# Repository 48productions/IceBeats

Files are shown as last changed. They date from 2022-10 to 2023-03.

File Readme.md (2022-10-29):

# IceBeats Music Visualizer
*"it's like a firebeat, but **cooler**"*

## Introduction
IceBeats is a Teensy-based lights driver board that does two things:
 - Works with StepMania to control cabinet and pad lights in a 573-era DDR cabinet.
 - Real-time, hardware independent music visualization across two LED strips.

The hardware is designed for minimal components/configuration for an embedded environment.
Grab a Teensy 3.2, a few addressable LED strips, and a few basic components, and you're done! No bloated bluetooth/wifi control or complex hardware setup required.

## Features
Code support for these are built-in - all 99% configurable, use any combination you like!

 * Visualization addressable LED strip - An addressable RGB LED strip for visualizations.
 * Bass addressable LED strip - Another addressable RGB LED strip, blinks to the beat.
 * Bass single-color LED strip/strand - Designed for a single-color LED strip, or low voltage LED string lights. Blinks to the beat.
     * Supports two-wire LED strands, where alternate LEDs/colors are driven by reversing the strip polarity using a H-Bridge, like the L293D. These are cheap and readibly available off places like Amazon.

 * Accepts audio input via RCA/mono 3.5mm jack (or with modification, any other input the Teensy audio library supports)
 * Designed around Teensy 3.2, other Audio-capable Teensy boards likely compatible (the 4.0 is untested but may work)
 
 * FFT-based music visualization using the Teensy Audio Library
 * Multiple visualization effects and color palettes. Optional dynamic, music-based color palettes available
 * Idle animations for when no music is playing
 
 * Drives 573-era DanceDanceRevolution cabinet/pad lighting (reads SextetStream-formatted data output by StepMania or other programs).
 * PCB design

## Hardware Setup
**Pin numbers and LED strip lengths can ALL be configured in `IceBeats.ino` - the settings are at the top!**

### Audio Input
Audio input is taken via a 3.5mm/RCA jack. [Wiring instructions can be found on the Teensy Audio Design Tool](https://www.pjrc.com/teensy/gui/?info=AudioInputAnalog)'s info panel for AudioInputAnalog.

### Visualization LED strip:
The main attraction, music visualization on an addressable LED strip!

Any WS2812/NeoPixel strip will do here (default: 54 pixels long, but can be configured for shorter/longer strips).
Excessive pixel count may cause performance drops.

### Bass LED strip:
This blinks to the beat with a strip-wide gradient, occasionally changing colors.

Again, use any WS2812/NeoPixel strip (default: 128 pixels. This can be made shorter/longer too)

### Bass light strand:
This one just blinks to the beat! You've got a few options for this:

For a single-color LED strip/string, one PWM pin is used for setting the strip's brightness, just hook it up to a mosfet/transistor and you're good to go.
  
Some cheap LED strings on Amazon will control alternate LEDs, or different LED colors by reversing the strip polarity.
If you have one of these strings, a L293D can be used to drive the strip at two different polarities to turn on alternate LEDs/colors.
Another pin can optionally connect to a L293D to do this. You will need to invert that pin's signal via a transistor, inverter, etc to drive the second input on the L293D.

### StepMania pad/cab light control:
This code accepts input over serial for any games/tools that use the SextetStream protocol for driving DDR cabinet/pad lights.

In the case of StepMania, this means either using the SextetStreamToFile (Linux) or Win32Serial (Windows) lights driver.

The light states are sent to the rest of the Teensy's IO pins. Ideally, these should connect to the DDR cabinet through opto isolators. No transistor/mosfet is needed here, the stock DDR cabinet amp handles the high-current loads.

Lights data can optionally be output to three shift registers, as well, if you need more light outputs than the Teensy has pins.

## Todo:
 There's a lotta things that could be improved
 * Better documentation/wiring instructions
 * A few bugfixes with idle animations on the main led strip
 * Better beat detection
 * Getting the visualizations to look like they reflect the music a bit closer
 * More color palettes.

## License
I'd greatly apprecate it if you credit/link back to this repo if you use this code somewhere - this thing took a TON of time to make.

That being said,

¯\\_(ツ)_/¯

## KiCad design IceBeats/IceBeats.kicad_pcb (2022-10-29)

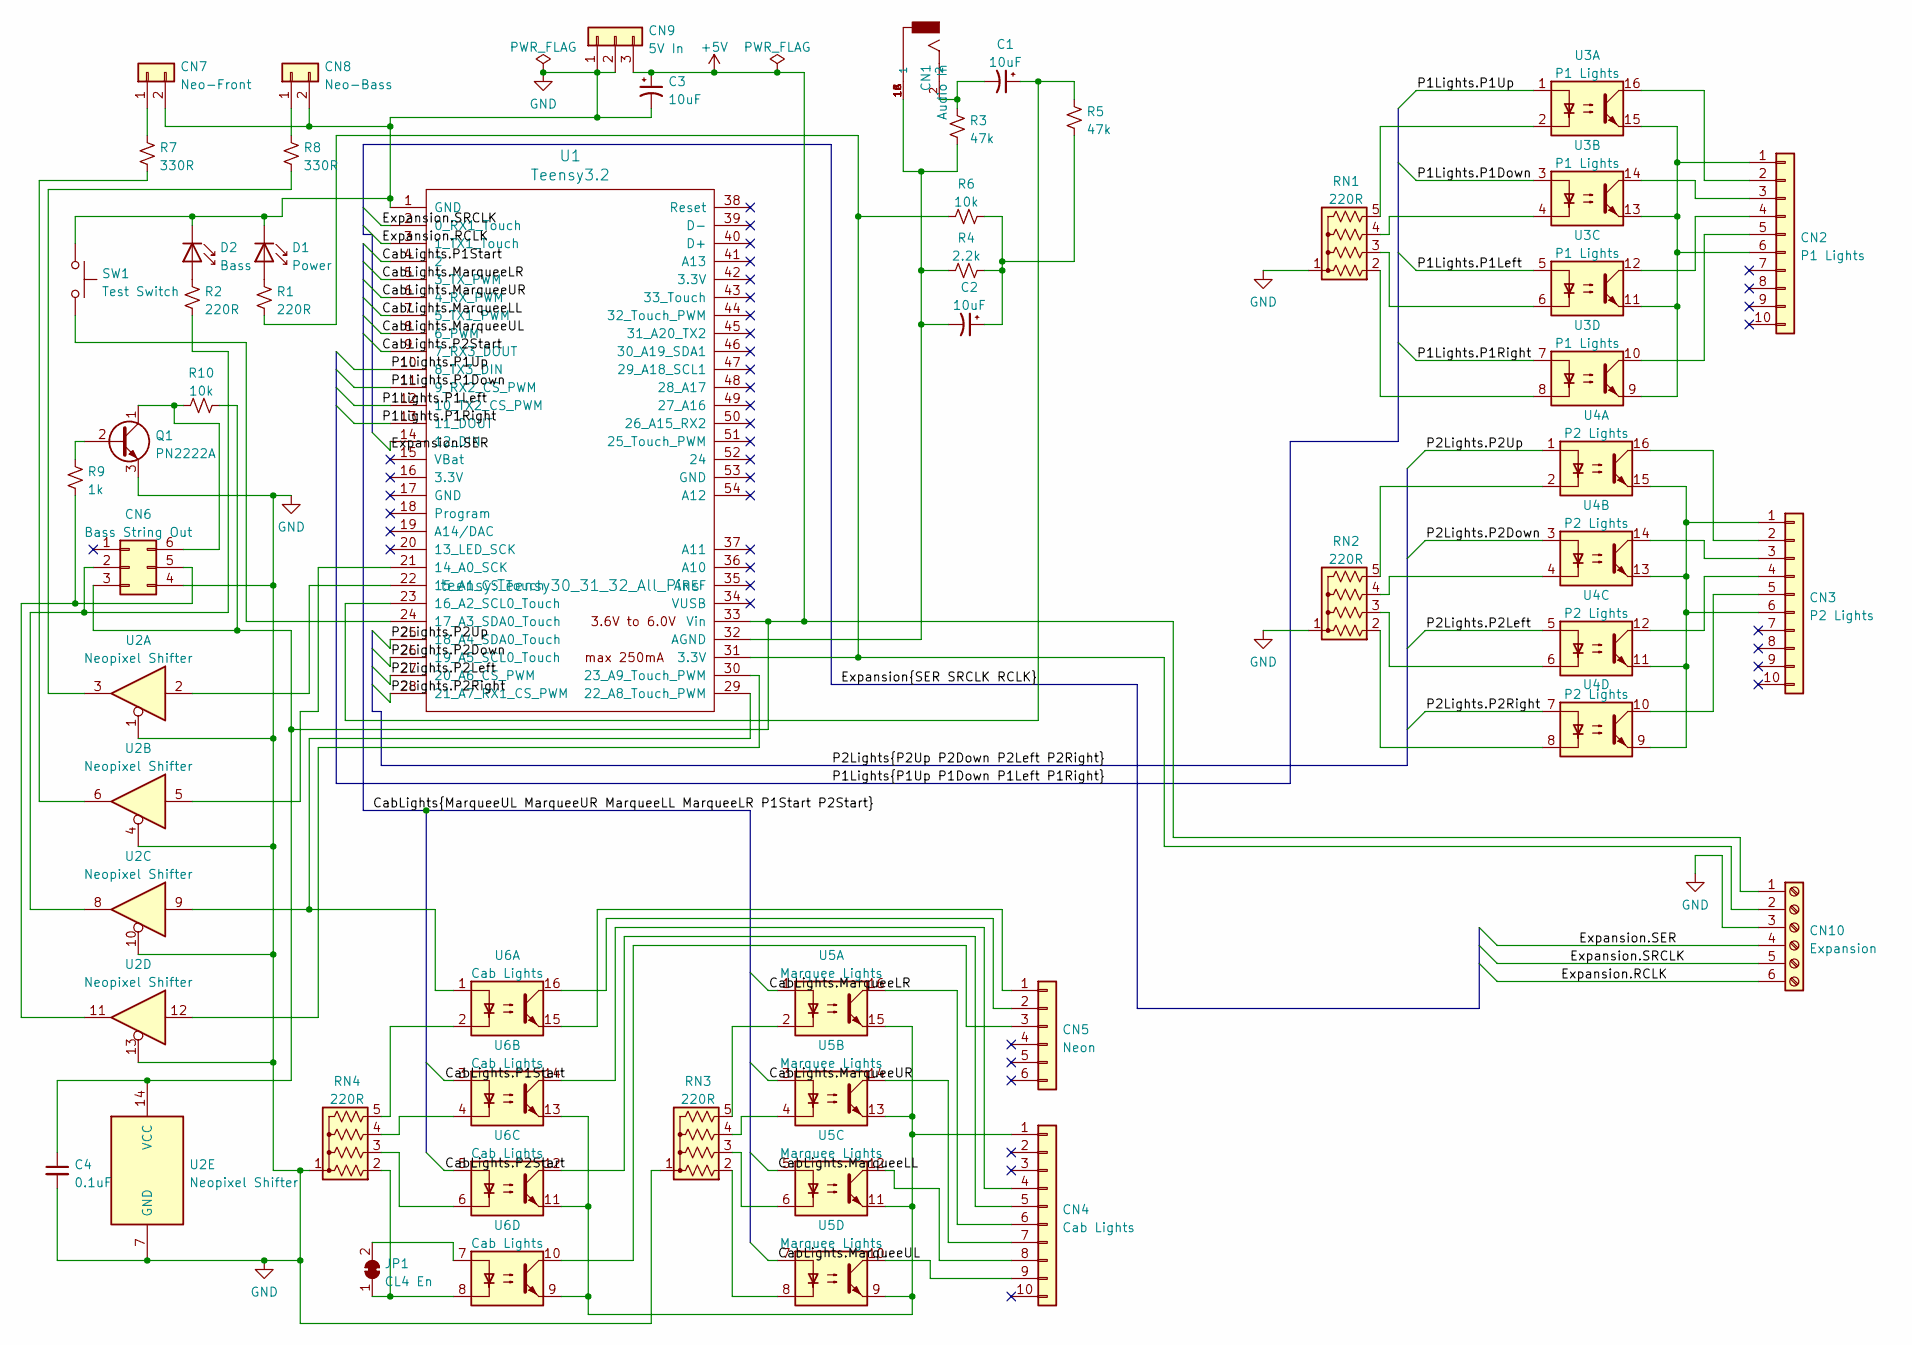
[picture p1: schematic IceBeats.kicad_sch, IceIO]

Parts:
C1, C2, C3: 10uF; CP_Radial_D6.3mm_P2.50mm
C4: 0.1uF; C_Disc_D5.1mm_W3.2mm_P5.00mm
CN1: Audio In; CUI_RCJ-013; PART_REV B
CN2: P1 Lights; PinHeader_1x10_P2.54mm_Vertical
CN3: P2 Lights; PinHeader_1x10_P2.54mm_Vertical
CN4: Cab Lights; PinHeader_1x10_P2.54mm_Vertical
CN5: Neon; PinHeader_1x06_P2.54mm_Vertical
CN6: Bass String Out; IDC-Header_2x03_P2.54mm_Vertical
CN7: Neo-Front; Molex_KK-254_AE-6410-02A_1x02_P2.54mm_Vertical
CN8: Neo-Bass; Molex_KK-254_AE-6410-02A_1x02_P2.54mm_Vertical
CN9: 5V In; Molex_KK-254_AE-6410-03A_1x03_P2.54mm_Vertical
CN10: Expansion; PinHeader_1x06_P2.54mm_Vertical
D1: Power; LED_D3.0mm_Horizontal_O3.81mm_Z2.0mm
D2: Bass; LED_D3.0mm_Horizontal_O3.81mm_Z2.0mm
JP1: CL4 En; SolderJumper-2_P1.3mm_Bridged_RoundedPad1.0x1.5mm
Q1: PN2222A; TO-92_HandSolder
R1, R2: 220R; R_Axial_DIN0207_L6.3mm_D2.5mm_P2.54mm_Vertical
R3: 47k; R_Axial_DIN0207_L6.3mm_D2.5mm_P2.54mm_Vertical
R4: 2.2k; R_Axial_DIN0207_L6.3mm_D2.5mm_P10.16mm_Horizontal
R5: 47k; R_Axial_DIN0207_L6.3mm_D2.5mm_P10.16mm_Horizontal
R6, R10: 10k; R_Axial_DIN0207_L6.3mm_D2.5mm_P10.16mm_Horizontal
R7, R8: 330R; R_Axial_DIN0207_L6.3mm_D2.5mm_P10.16mm_Horizontal
R9: 1k; R_Axial_DIN0207_L6.3mm_D2.5mm_P10.16mm_Horizontal
RN1, RN2, RN3, RN4: 220R; R_Array_SIP5
SW1: Test Switch; SW_PUSH_6mm_H5mm
U1: Teensy3.2; Teensy30_31_32_All_Pins
U2: Neopixel Shifter; DIP-14_W7.62mm_Socket
U3: P1 Lights; DIP-16_W7.62mm
U4: P2 Lights; DIP-16_W7.62mm
U5: Marquee Lights; DIP-16_W7.62mm
U6: Cab Lights; DIP-16_W7.62mm

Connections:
+5V: C3.1, C4.1, CN6.3, CN9.3, CN10.1, R10.1, U1.33 (Vin), U2.14 (VCC)
/CabLights.MarqueeLL: U1.7 (5_TX1_PWM), U5.5
/CabLights.MarqueeLR: U1.5 (3_TX_PWM), U5.1
/CabLights.MarqueeUL: U1.8 (6_PWM), U5.7
/CabLights.MarqueeUR: U1.6 (4_RX_PWM), U5.3
/CabLights.P1Start: U1.4 (2), U6.3
/CabLights.P2Start: U1.9 (7_RX3_DOUT), U6.5
/Expansion.RCLK: CN10.6, U1.3 (1_TX1_Touch)
/Expansion.SER: CN10.4, U1.14 (12_DIN)
/Expansion.SRCLK: CN10.5, U1.2 (0_RX1_Touch)
/P1Lights.P1Down: U1.11 (9_RX2_CS_PWM), U3.3
/P1Lights.P1Left: U1.12 (10_TX2_CS_PWM), U3.5
/P1Lights.P1Right: U1.13 (11_DOUT), U3.7
/P1Lights.P1Up: U1.10 (8_TX3_DIN), U3.1
/P2Lights.P2Down: U1.26 (19_A5_SCL0_Touch), U4.3
/P2Lights.P2Left: U1.27 (20_A6_CS_PWM), U4.5
/P2Lights.P2Right: U1.28 (21_A7_RX1_CS_PWM), U4.7
/P2Lights.P2Up: U1.25 (18_A4_SDA0_Touch), U4.1
GND: C3.2, C4.2, CN6.4, CN7.2, CN8.2, CN9.1, CN9.2, CN10.3, D1.1 (K), D2.1 (K), Q1.3 (E), RN1.1 (common), RN2.1 (common), RN3.1 (common), RN4.1 (common), SW1.1, U1.1 (GND), U2.1, U2.4, U2.7 (GND), U2.10, U2.13
unnamed: C1.1, R5.1, U1.23 (16_A2_SCL0_Touch)
unnamed: C1.2, CN1.2, R3.1
unnamed: C2.1, R4.1, R5.2, R6.1
unnamed: C2.2, CN1.1A (1), CN1.1B (1), CN1.1C (1), R3.2, R4.2, U1.32 (AGND)
unnamed: CN2.1, CN2.6, U3.9, U3.11, U3.13, U3.15
unnamed: CN2.2, U3.16
unnamed: CN2.3, U3.14
unnamed: CN2.4, U3.12
unnamed: CN2.5, U3.10
unnamed: CN3.1, CN3.6, U4.9, U4.11, U4.13, U4.15
unnamed: CN3.2, U4.16
unnamed: CN3.3, U4.14
unnamed: CN3.4, U4.12
unnamed: CN3.5, U4.10
unnamed: CN4.1, U5.9, U5.11, U5.13, U5.15, U6.9, U6.11, U6.13
unnamed: CN4.4, U6.14
unnamed: CN4.5, U6.12
unnamed: CN4.6, U5.16
unnamed: CN4.7, U5.14
unnamed: CN4.8, U5.12
unnamed: CN4.9, U5.10
unnamed: CN5.1, U6.15
unnamed: CN5.2, U6.16
unnamed: CN5.3, U6.10
unnamed: CN6.2, R2.2, U2.8
unnamed: CN6.5, R9.2, U2.11
unnamed: CN6.6, Q1.1 (C), R10.2
unnamed: CN7.1, R7.1
unnamed: CN8.1, R8.1
unnamed: CN10.2, R1.2, R6.2, U1.31 (3.3V)
unnamed: D1.2 (A), R1.1
unnamed: D2.2 (A), R2.1
unnamed: JP1.1 (A), RN4.2 (R1), U6.8
unnamed: JP1.2 (B), U6.7
unnamed: Q1.2 (B), R9.1
unnamed: R7.2, U2.6
unnamed: R8.2, U2.3
unnamed: RN1.2 (R1), U3.8
unnamed: RN1.3 (R2), U3.6
unnamed: RN1.4 (R3), U3.4
unnamed: RN1.5 (R4), U3.2
unnamed: RN2.2 (R1), U4.8
unnamed: RN2.3 (R2), U4.6
unnamed: RN2.4 (R3), U4.4
unnamed: RN2.5 (R4), U4.2
unnamed: RN3.2 (R1), U5.8
unnamed: RN3.3 (R2), U5.6
unnamed: RN3.4 (R3), U5.4
unnamed: RN3.5 (R4), U5.2
unnamed: RN4.3 (R2), U6.6
unnamed: RN4.4 (R3), U6.4
unnamed: RN4.5 (R4), U6.2
unnamed: SW1.2, U1.24 (17_A3_SDA0_Touch)
unnamed: U1.21 (14_A0_SCK), U2.5
unnamed: U1.29 (22_A8_Touch_PWM), U2.9, U6.1
unnamed: U1.30 (23_A9_Touch_PWM), U2.12
unnamed: U1.22 (15_A1_CS_Touch), U2.2

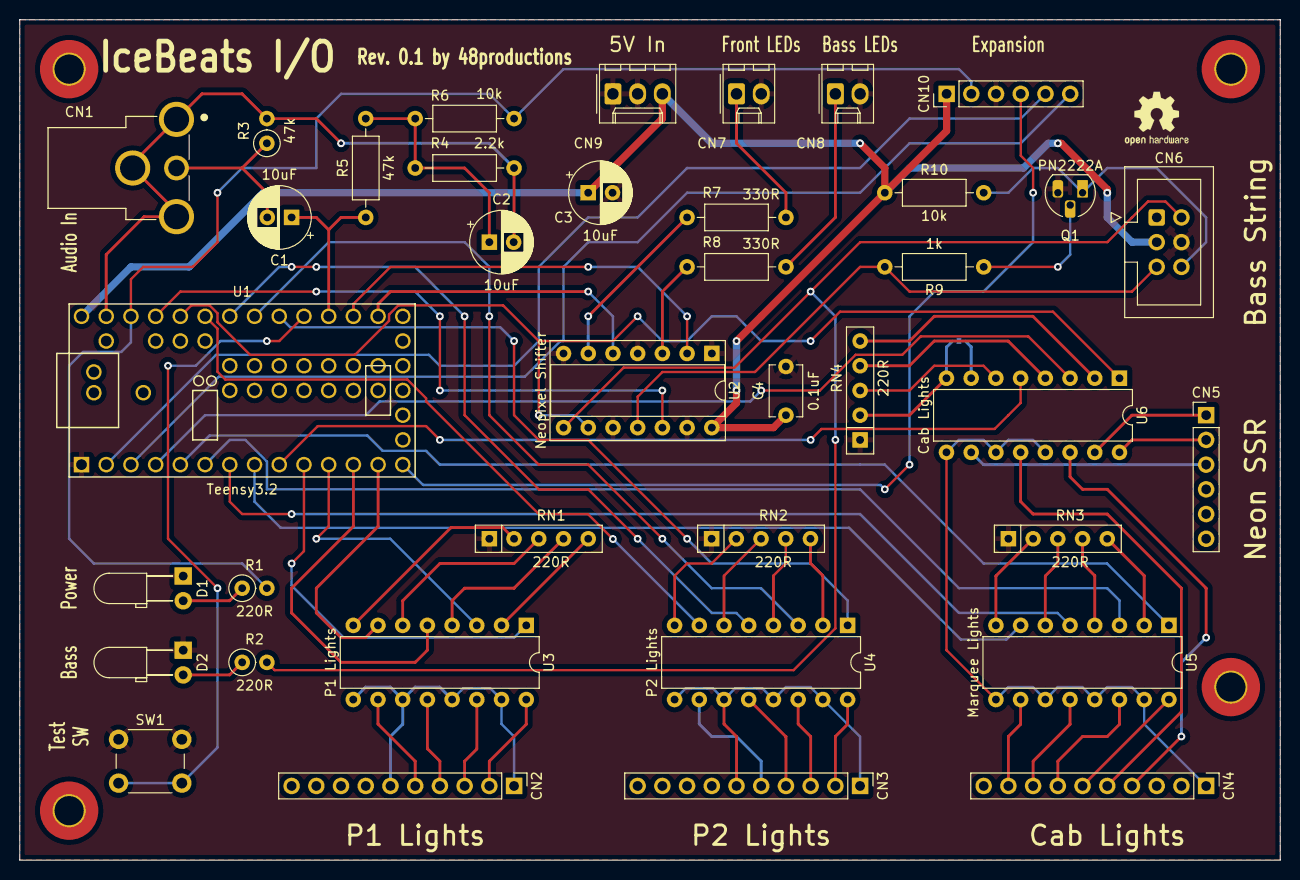
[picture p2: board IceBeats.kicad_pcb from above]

Board: 2 copper layers, 129.5 x 86.4 mm, 39 parts (1 on the bottom side), 76 nets.

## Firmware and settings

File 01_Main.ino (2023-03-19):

/********************
 *   01_MAIN.INO    *
 *******************/

 /**
  * Functions for setup and loop
  */


void setup() {
  //Keyboard.begin();
  
  AudioMemory(10);
  fft.windowFunction(AudioWindowHamming1024);
  
  Serial.begin(9600);
  LEDS.addLeds<WS2812, STRIP_DATA, GRB>(leds, STRIP_LENGTH);
  LEDS.addLeds<WS2812, STRIP_BASS_DATA, GRB>(ledsBass, STRIP_BASS_LENGTH);
  LEDS.setBrightness(94);

  pinMode(PIN_DEBUG_0, INPUT_PULLUP); //Pinmode ALL the pins
  pinMode(PIN_DEBUG_1, INPUT_PULLUP);
  pinMode(PIN_DEBUG_2, INPUT_PULLUP);
  pinMode(LED_BUILTIN, OUTPUT);
  
  pinMode(STRIP_DATA, OUTPUT);
  pinMode(PIN_BASS_LIGHT_1, OUTPUT);
  pinMode(PIN_BASS_LIGHT_2, OUTPUT);
  //pinMode(PIN_BASS_SEL_2, OUTPUT);

  #ifdef EXPANSION_SHIFT_REGISTERS
  pinMode(PIN_LIGHTS_LAT, OUTPUT);
  pinMode(PIN_LIGHTS_DAT, OUTPUT);
  pinMode(PIN_LIGHTS_CLK, OUTPUT);
  #else
  pinMode(PIN_P1_MENU, OUTPUT);
  pinMode(PIN_P2_MENU, OUTPUT);
  #endif

  pinMode(PIN_P1_UP, OUTPUT);
  pinMode(PIN_P1_DOWN, OUTPUT);
  pinMode(PIN_P1_LEFT, OUTPUT);
  pinMode(PIN_P1_RIGHT, OUTPUT);

  pinMode(PIN_P2_UP, OUTPUT);
  pinMode(PIN_P2_DOWN, OUTPUT);
  pinMode(PIN_P2_LEFT, OUTPUT);
  pinMode(PIN_P2_RIGHT, OUTPUT);

  pinMode(PIN_P1_START, OUTPUT);
  pinMode(PIN_P2_START, OUTPUT);
  pinMode(PIN_MARQUEE_LR, OUTPUT);
  pinMode(PIN_MARQUEE_UR, OUTPUT);
  pinMode(PIN_MARQUEE_LL, OUTPUT);
  pinMode(PIN_MARQUEE_UL, OUTPUT);

  setNewPalette(0); //Initialize palette-related variables

  bassChangeAverage.clear(); //Clear out running averages for the bass
  shortBassAverage.clear();
  shortNotBassAverage.clear();
  bassChangeAverage.addValue(0); //And add some initial data to the peak average
  averagePeak.clear();
  bassKickLengthAverage.clear();
}




void loop() {
  curMillis = millis();
  
  debug0.update();
  debug1.update();
  debug2.update();

  if (debug2.fell()) { //Debug 2 pressed, swap to a new color palette
    setNewPalette(curPaletteIndex + 1);
    lastPaletteSwap = curMillis;
  }

  if (debug1.fell()) { //Debug 1 pressed, swap to a new visualization effect
    setNewVE(curEffect + 1);
  }

  if (debug0.fell()) { //Debug 0 pressed, toggle lighting test mode
    lightTestEnabled = !lightTestEnabled;
    if (lightTestEnabled) { //Going into the light test, set some variables to prepare for it
      lightTestStartMillis = curMillis;
      writeBass(255);
      lightTestStripPos = 0;
      lightTestStripColor = 0;
      FastLED.clear(); //Clear the LED strip for the test:tm:
    }
  }

  if (Serial.available() > 0) { //Do we have lights data to receive?
    updateSerialLights();
  }

  if (curMillis >= lastUpdateMillis + 16) { //Time for an update, gotta keep a 60fps update rate
    //Serial.println(curMillis - lastUpdateMillis); //Debug: Print update rate
    /*Serial.print(" ");
    Serial.print(AudioProcessorUsage());
    Serial.print(" ");
    Serial.println(AudioMemoryUsage());*/
    lastUpdateMillis = curMillis;


#ifdef USE_PRESET_PALETTES //If using preset color palettes, check if we recently swapped between palettes
    if (curMillis <= lastPaletteSwap + 150) { //If so, we should be fading between the old and the new colors
      short transProgress = ((float)(curMillis - lastPaletteSwap) / 150) * 255;
      //Serial.println(transProgress);
      for (int i = 0; i <= 3; i++) {
        curPalette[i] = blend(lastPalette[i], palettes[curPaletteIndex][i], transProgress); //Blend between the last and current palettes over the course of our fade duration (100ms)
      }
      
    } else { //If we're not fading between the old/new palettes, waver the current one's hue
      int targetAnimLength = bassKickLengthAverage.getAverage() * 2; //First find out how long this waver should last (2x length between bass kicks)
      float waverPos = ((float)(curMillis - lastHueWaverMillis) / targetAnimLength) * PI; //Next, our position into the waver sine wave...
      if (waverPos >= 2 * PI) { lastHueWaverMillis = curMillis; } //(Also set the last time we completed a waver if we've just completed a waver)
      short waverVal = sin(waverPos) * HUE_WAVER_STRENGTH; //...and finally use sine to calculate how much we should offset the hue
      /*Serial.print(waverPos);
      Serial.print(" ");
      Serial.println(waverVal);*/
      for (int i = 0; i <= 3; i++) {
        curPalette[i].h += waverVal; //Now modify the current palette's hue based on our calculated value
      }
    }
    updateAltPalettes();
#endif

    /*for (int i = 0; i <= 3; i++) { //Handle smooth fading for the marquee lights
      if (marqueeOn[i] && marqueeBrightness[i] < 1) { //If we still need to fade on this light...
        marqueeBrightness[i] = min(marqueeBrightness[i] * 2.75, 1); //...increment its brightness (but cap it at 1)
        //Serial.println(marqueeBrightness[i]);
        //analogWrite(pinLightsMarquee[i], marqueeBrightness[i] * 255); //My cab said no to smooth fading marquee lights, so writing to pins is disabled but the rest of the code is left enabled since VE Pulse uses these values
        
      } else if (!marqueeOn[i] && marqueeBrightness[i] > 0) { //What if we need to fade OFF this light?
        marqueeBrightness[i] = max(marqueeBrightness[i] * 0.6, 0.01); //...decrement its brightness (but prevent it from going below 0)
        //analogWrite(pinLightsMarquee[i], marqueeBrightness[i] * 255);
      }
    }*/
    
    if (lightTestEnabled) { //In the lighting test, update some lights boi
      updateLightTest();
      
    } else { //Not in the lighting test, update visualizations/idles/etc
      if ((idling && idlePos < 1) || !idling) { //If we're not idling or idling without playing an idle animation, update the bass strip
        updateBassStrip();
      }
      
      if (peak.available()) { //We have peak data to read! READ IT!
        updatePeak();
      }
    
      if (!idling && fft.available()) { //FFT has new data and we aren't idling, let's visualize it!
        updateVisualization();
        
      } else if (idling && idlePos >= 1 && curMillis - lastIdleUpdateMillis >= idleUpdateMs) { //We're idling, playing the idle animation, and it's time for an update!
        updateIdleAnim();
        
      } else if (idling && idlePos < 1) { //Not running a visualization or idle animation (either finished an idle or just stopped getting sound), just fade out the strip and bass lightsthis cycle
        updateIdle();
      }
    }
  }

  /*Serial.print(curMillis);
  Serial.print(" ");
  Serial.print(lastHeartbeatFlipMs);
  Serial.print(" ");
  Serial.println(lastUpdateMillis);*/
  
  if (curMillis - lastHeartbeatFlipMs >= 500) { //500ms since the heartbeat LED toggled states, toggle it now!
    heartbeatState = !heartbeatState;
    lastHeartbeatFlipMs = curMillis;
    digitalWrite(LED_BUILTIN, heartbeatState);
  }

  
  //delay(10);
}

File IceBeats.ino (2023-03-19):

/*****************************
   ICEBEATS MUSIC VISUALIZER
 ****************************/

//#define NO_CORRECTION 1
#define FASTLED_ALLOW_INTERRUPTS 0 //Required for longer strips (required for 90 LEDs, but not for 60)
#include "FastLED.h"

#include <Audio.h>
#include <Wire.h>
#include <SPI.h>
#include <SD.h>
#include <SerialFlash.h>

#include <Bounce2.h>
#include "RunningAverage.h"
//#include <Keyboard.h>




/*****************
   CONFIGURATION
 ****************/

// ADDRESSABLE LED CONFIGURATION
#define STRIP_LENGTH 54 //Number of LEDs in the strip (warning: Adding many LEDs slows updates)
#define STRIP_DATA 14 //Pin connected to the LED strip

#define STRIP_BASS_LENGTH 128 //Number of LEDs in our bass neon strip
#define STRIP_BASS_DATA 15 //Pin connected to the bass neon strip

//Set this next option to true to make bass strip effects start in the center and wipe outwards (instead of starting at the edges and wiping inwards)
//IceBeats was designed for the bass strip to be wrapped around a subwoofer with effects starting at the bottom of the sub and climbing towards the top
//This value compensates for whether the ends of this strip are mounted at the top (true) or bottom (false) of the sub
#define INVERT_BASS_STRIP_POS false


// EXPANSION PORT CONFIGURATION
// The expansion port currently has two modes:
// Option A: Comment out the below line to drive an extra 3 cab lights off of the expansion port (currently configured for P1/P2 Menu lights)
// Option B: Uncomment the below line to output cab/pad lighting data to shift registers attached to the expansion port
//#define EXPANSION_SHIFT_REGISTERS true


// VISUALIZATION CONFIGURATION
#define USE_PRESET_PALETTES true //Set whether to use pre-set or base palettes off of the music. Pre-set is more visually pleasing, music-based may reflect changes in music better
#define HUE_WAVER_STRENGTH 1.5 //When using preset palettes, the hue of the current palette will "waver" slightly to the beat of the music. This controls how strong this waver is (0 - none, 2 - strong)


// CAB LIGHT CONFIGURATION
#define PIN_BASS_LIGHT_1 22 //PWM-able pins for the bass string
#define PIN_BASS_LIGHT_2 23 //My setup uses an LED light string where alternating LEDs are driven by reverse polarities (drive at +29V for even lights, -29V for odd lights).
//#define PIN_BASS_SEL_2 24 //These are driven using an H-bridge, which use 2 pins control which set of lights are turned on.
// (previously used one pin for enable and two for direction (L298), now uses one for each direction (DRV8871). You can also drive two single color LED strips or similar)

#define PIN_DEBUG_0 17 //Lighting test button
#define PIN_DEBUG_1 A14 //Swap visualization button
#define PIN_DEBUG_2 25 //Swap palette button (there if you need it)

// Configure pins for the expansion port shift registers (top) or expansion port menu lights (bottom)
#ifdef EXPANSION_SHIFT_REGISTERS
#define PIN_LIGHTS_LAT 1 //Pins for the latch, clock, and data lines for the lighting shift registers, if shift register output is enabled above
#define PIN_LIGHTS_CLK 0 //(Default: Mapped to the Expansion pins on the IceBeats I/O PCB)
#define PIN_LIGHTS_DAT 12

#else
#define PIN_P1_MENU 0 // P1 Menu Left/Right (expansion port pin 5)
#define PIN_P2_MENU 1 // P2 Menu Left/Right (expansion port pin 6)
#endif

#define PIN_P1_UP 8
#define PIN_P1_DOWN 9
#define PIN_P1_LEFT 10
#define PIN_P1_RIGHT 11

#define PIN_P2_UP 18
#define PIN_P2_DOWN 19
#define PIN_P2_LEFT 20
#define PIN_P2_RIGHT 21

#define PIN_P1_START 2
#define PIN_P2_START 7
#define PIN_MARQUEE_LR 3
#define PIN_MARQUEE_UR 4
#define PIN_MARQUEE_LL 5
#define PIN_MARQUEE_UL 6

// Debugging
#define DEBUG_FFT_BINS true //Set true to test FFT section responsiveness - bin sections are mapped to the brightness of specific pixels
#define DEBUG_BURNIN false //Set to true to enable the light test at boot, and to disable the 


/*****************
   EFFECT CONFIG
 ****************/

const int STRIP_HALF = STRIP_LENGTH / 2; //Convinience variables for half/4th/etc of the strip length
const int STRIP_FOURTH = STRIP_LENGTH / 4;
const int STRIP_6TH = STRIP_LENGTH / 6;
const int STRIP_8TH = STRIP_LENGTH / 8;
const int STRIP_16TH = STRIP_LENGTH / 16;
const int STRIP_32ND = STRIP_LENGTH / 32;

const int STRIP_BASS_HALF = STRIP_BASS_LENGTH / 2; //Half length of the bass strip
const float BASS_DELTA = 65.0 / STRIP_BASS_HALF; //Controls strip-wide hue shifts for bass visualizations (higher number = more rainbow for bass kicks)

const int PULSE_MAX_SIZE_BASS = STRIP_LENGTH / 6; //Maximum section sizes for Visualization Effect Pulse (based on strip length)
const int PULSE_MAX_SIZE_LOW = STRIP_LENGTH / 8;
const int PULSE_MAX_SIZE_MID = STRIP_LENGTH / 8;
const int PULSE_MAX_SIZE_HIGH = STRIP_LENGTH / 8;

const int PUNCH_MAX_SIZE_BASS = STRIP_LENGTH / 6; //Maximum section sizes for Visualization Effect Punch
const int PUNCH_MAX_SIZE_LOW = STRIP_LENGTH / 8;
const int PUNCH_MAX_SIZE_MID = STRIP_LENGTH / 8;
const int PUNCH_MAX_SIZE_HIGH = STRIP_LENGTH / 8;

const int KICK_MAX_SIZE_BASS = STRIP_LENGTH / 6; //Maximum section sizes for Visualization Effect Kick
const int KICK_MAX_SIZE_SECTION = STRIP_LENGTH / 8;

const int VOLUME_MAX_SIZE_BASS = STRIP_LENGTH / 4; //Maximum section sizes for Visualization Effect Volume
const int VOLUME_MAX_SIZE_LOW = STRIP_LENGTH / 10;
const int VOLUME_MAX_SIZE_MID = STRIP_LENGTH / 10;
const int VOLUME_MAX_SIZE_HIGH = STRIP_LENGTH / 10;

const int PITCH_SECTION_SIZE = STRIP_HALF / 3; //Section size for VE Pitch's palette gradients
const double PITCH_BIN_EXP = log10(511) / STRIP_HALF; //Magic number used to help calculate a curve to determine the number of FFT bins per pixel in VE Pitch (More documentation below)

const short COMMON_FREQ_MIN = (log10(4) / PITCH_BIN_EXP) - 1; //The first and last LED brightness indexes from VE Pitch's brightness function to use for common frequency calculation
const short COMMON_FREQ_MAX = (log10(42) / PITCH_BIN_EXP) - 1; //(For these, we're finding the pixels where FFT bins 4 and 36 are)




/**********************
   HARDWARE VARIABLES
 *********************/

//Audio setup: Uses ADC for input, then uses the magic of software for the following steps:
// ADC goes into amp, amp output goes into objects to detect audio peaks and FFT analysis

// GUItool: begin automatically generated code
AudioInputAnalog         adc;           //xy=274,198
AudioAmplifier           amp;           //xy=333,187
AudioAnalyzePeak         peak;          //xy=431,178
AudioAnalyzeFFT1024       fft;       //xy=436,222
AudioConnection          patchCord1(adc, amp);
AudioConnection          patchCord2(amp, fft);
AudioConnection          patchCord3(amp, peak);
// GUItool: end automatically generated code

CRGB leds[STRIP_LENGTH];
CRGB ledsBass[STRIP_BASS_LENGTH];
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

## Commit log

2020-07-25 Effect Kick no longer sucks, other effect improvements
    Lots of changes to make visualization effects not be trash!
    - Kick now always draws non-bass sections across the entire strip, and fits more non-bass sections on the strip
    - Kick's bass section is now overlaid on top of whatever the rest of the strip is doing
    - Pulse and Punch now pulse the strip's brightness to the beat
    - Bass kicks are visualized on the built-in LED on the Teensy
    - TODO: Beat detection is still buggy as frick
    [IceBeats.ino]
2020-07-30 IceBeats: Now with AGC and better beat detection!
    * Songs should visualize similarly regardless of the input's volume - hyper quiet songs no longer only turn on 1 LED, hyper loud songs no longer always max out all the LEDs
    * The threshold to detect a beat at now decreases if beats aren't seen for a bit
    [IceBeats.ino]
2020-08-04 Cabinet button input, improved other stuff
    - Inputs on some specific pins (tentative, likely to change) now send keystrokes
    - /shrug, everything else seems better now too
2020-08-11 "Driving input with my lights driver is probably a dumb idea"
    Also made idle animations functional and implemented an idle animation :ok_hand:
2020-08-14 SIGNIFICANTLY improved beat detection
    - Pros: New bass kick detection method, based on tracking how much the bass changes each FFT read and how far above this average the current bass change is
    - Cons: No longer works on Brain Power
    - Pros: Works at least decently well on most of the songs I've tried so far
    - Cons: No really this method doesn't work on Brain Power please don't try it :(
    [IceBeats.ino]
2020-08-18 Add light test, tweak beat detection
    - Added light test mode - Blinks all lights and cycles colors on the LED strip
    - Beat detection handles quieter songs better
    - Bass kick length is now dynamic and based on the music (with an upper limit) instead of being hard coded to 125ms
    - Fixed some beat-based effects in VEPulse/VEPunch
    - Section brightness in VE Kick now depends on how loud that section is
    [IceBeats.ino]
2020-08-28 Volume control, cabinet lighting
    Also pin reassignments lol, cab lighting currently untested
2020-09-01 Better AGC, maybe better beat detection?
    - Added Visualization Effect: Volume
    - Gently coax AGC to actually work (compensation for low cab/song volume - Great if your speakers are turned down to 1 but you still want LED brightness turned up to 11)
    - Implemented detection for the current non-bass FFT level - If this level is lower than average, bass kick detection is made slightly more lenient (Though not by much yet, thanks to Yumry for the su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
2020-09-16 tfw you break your board design
2020-09-17 Add burn-in, unfinished exp. filtering
    [IceBeats.ino]
2020-09-18 My code is not ready
    - Reversed volume up/down pins
    - *Hopefully* disabled fancy marquee lighting (my cab said no, away it goes)
    [IceBeats.ino]
2020-10-07 VE Pitch actually kinda works now
    Todo: Bass is overemphasized, mids should be emphasized more
2020-10-18 Experimental palette swapping - Very buggy
    Disable more fancy cab light stuff
    [IceBeats.ino]
2020-10-30 Make VE Pitch look nicer
    ...but not perfect.
    Also tweak the "big change in music" detection to not be ultra spazzy.
2020-11-04 Frequency -> Color = Maybe??? (WIP, broken)
    - Pitch LED offset tidy
    - A generic-ish "frequency to color" conversion is done. In the future this might help decide color palettes. For now, it's mapped to pixel #0.
    TODO: Less temporary hardcoded jank, more actually working code (like always)
    [IceBeats.ino]
2020-11-09 Frequency -> Color? (Suggested by Yumry), BIG tidy
    - The strip palette is now based on a common frequency -> color conversion (experimental, thanks Yumry for the suggestion!)
    - Big code tidy the second: Main loop update functions are in their own ino file now, let's break git because why not lol.
    - Stop writing outside of arrays in the common frequency detection (Fixes glitchiness in VE Kick, I WARNED you about the ARRAYS, DOG!)
    [01_Main.ino, 02_Update_Funcs.ino, 03_FFT_Utils.ino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]
2020-11-16 Big Tidy MK.3: Faster, less ghetto visualization update rate
    Big Tidy MK.3: The main loop's update rate was dependent on both a delay() call and how fast the FFT could update - pretty jank.
    Now we're 100% dependent on keeping a solid 60fps, which I'm assuming will translate to improvements elsewhere (like the update-rate dependent beat detection). :ok_hand:
    Some fun facts about how fast updates happen:
    - Before: Every 20-24ish ms (40-50fps)
    - No delays: 10-15ms (66-100fps)
    - Current: Fairly smooth 16ms (60fps)
    - These numbers are the same regardless of the VE in use, somehow. Adding more LEDs for FastLED to use didn't do much either.
    [01_Main.ino, 02_Update_Funcs.ino, IceBeats.ino]
2020-11-17 Partial bass LED strip support
    I tried before and failed. Now that things are a tad less buggy, let's goooo!
    (Todo: Stepmania control)
    Also: Rewrite readme, tweak beat detection since we're running at a different update rate now
    [01_Main.ino, 03_FFT_Utils.ino, 05_Strip_Utils.ino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]
2020-11-24 Auto visualization swapping, AGC tweak
    [02_Update_Funcs.ino]
2020-12-02 SM-Controlled Bass Neon LED Strip
    - The bass neon LED strips automagically switch between SM and audio reactive control
    - Cleanup of bass led strip code
2020-12-17 Make music-based palettes an option
    - Choosing between music-based and pre-set color palettes is now an option
    - Pre-set color palettes now auto-swap
    - Disabled more fadeable marquee light garbage
    [01_Main.ino, 02_Update_Funcs.ino, 05_Strip_Utils.ino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]
2021-01-04 Alternative SM-based VE (to be removed)
    An experimental, half-broken rewrite of VE Pulse to blink four strip sections to SM's marquee lighting output, also brings back marquee light fading (internally) and adds smoother fades on/off to it.
    It's not a *terrible* effect in-game, but it's not great in menus and wouldn't look good if it was reading marquee lighting from non-stepmania games (say, if I read lighting output from a 573 - real DDR doesn't do anything really interesting).
    Away it goes eventually, but committing so that it's at least saved somewhere before being nuked into oblivion.
    [01_Main.ino, 02_Update_Funcs.ino, 06_Visualizations.ino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]
2021-01-11 Memory tweaks, bass LED strip tweak
    - Reduce memory allocation for the audio library (only really used like half the memory I allocated for it, it seems)
    - Flip the direction the bass LED strip draws in
    - Disable keyboard support
    There's some leftover code from trying to troubleshoot an issue where too many LEDs on the bass LED strip completely borks several millis-related things. *Not* using oodles of pixels is a hard sell, so more troubleshooting is incoming. Maybe FastLED is taking too long to write out 190 WS2812s?
    [01_Main.ino, 02_Update_Funcs.ino, 06_Visualizations.ino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]
2021-01-14 MMMMMMMMMMMMMMMMMMMMMMMMMMM
    The data array for the bass LED strip is now initialized properly
    This fixes a bug where if the bass LED strip was made longer than the main one, random values would get written into millis and completely NUKE a heckton of other functionality.
    [IceBeats.ino]
2021-01-14 Light test, bass kick scroll improvements
    - Light test now tests both strips, and has a rainbow test
    - Two positions/colors for bass kick scrolling LEDs are now tracked
2021-02-07 New bass LED strip VE, cleanup
    - Tried to make a new VE again (haha nope)
    - Cleaned bass kick LED scrolling code a tad
    - Bass LED strip effects that alter the hue across the strip now scale with strip size
    - Bass kicks on the bass LED strip can be visualized in two slightly different ways now
2021-02-10 Fade between palette changes
    - Palette changes now briefly fade between the old and new palettes
    - Random palette swaps will no longer swap from one palette to the exact same palette
    [01_Main.ino, 02_Update_Funcs.ino, 05_Strip_Utils.ino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]
2021-02-20 Experimental: Waver the current palette's hue to the beat
    - In preset palette mode, the palette in use is now wavered a tad (vaguely) to the beat to add some more flavor to visualizations. This is mostly proof of concept, probably gonna get polished some more later.
    - The last bass kick timestamp is now reset when exiting idle (throws off bass kick length calculation for a bit otherwise)
    [01_Main.ino, 02_Update_Funcs.ino, IceBeats.ino]
2021-02-24 Bass strip polishing
    - Default to 144-long bass strips again
    - Strip hue waver is now configurable
    - The position on the bass strip that effects start at (edges or center) is now also configurable
    - Bass strip hue shift config tweaked, now allows for more granularity (hue shift went from short to float)
    [01_Main.ino, 02_Update_Funcs.ino, IceBeats.ino]
2021-02-24 Fix bass hue offset bug
    [02_Update_Funcs.ino]
2021-02-28 Fix most serial lighting outputs being broken
    Meme output commit was too way memey. Your guess as to why it broke is as good as mine, but apparently Arduino *really* didn't want to bitRead directly into variables.
    [02_Update_Funcs.ino]
2021-06-11 More pinout changes
    This week on "48 rewires his DDR cab for the 50th time": Marquee/button lighting has a new pinout for questionable reasons!
2022-10-29 Add IceBeats I/O PCB
    NEW! PCB design for those interested in an I/O solution better than just parts on a perfboard!
    - Add KiCad schematics for I/O PCB
    - Modify firmware to accompany I/O PCB - light outputs no longer require shift registers
    - Accompanying documentation update
    [IceBeats.kicad_pcb, IceBeats.kicad_sch, IceBeats.sch]
2023-01-31 Fix lighting pinouts (not jank edition)
    [01_Main.ino, 02_Update_Funcs.ino]
2023-03-19 Rework Bass String H-Bridge for Adafruit DRV8871
    [01_Main.ino, 02_Update_Funcs.ino, 03_FFT_Utils.ino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]
